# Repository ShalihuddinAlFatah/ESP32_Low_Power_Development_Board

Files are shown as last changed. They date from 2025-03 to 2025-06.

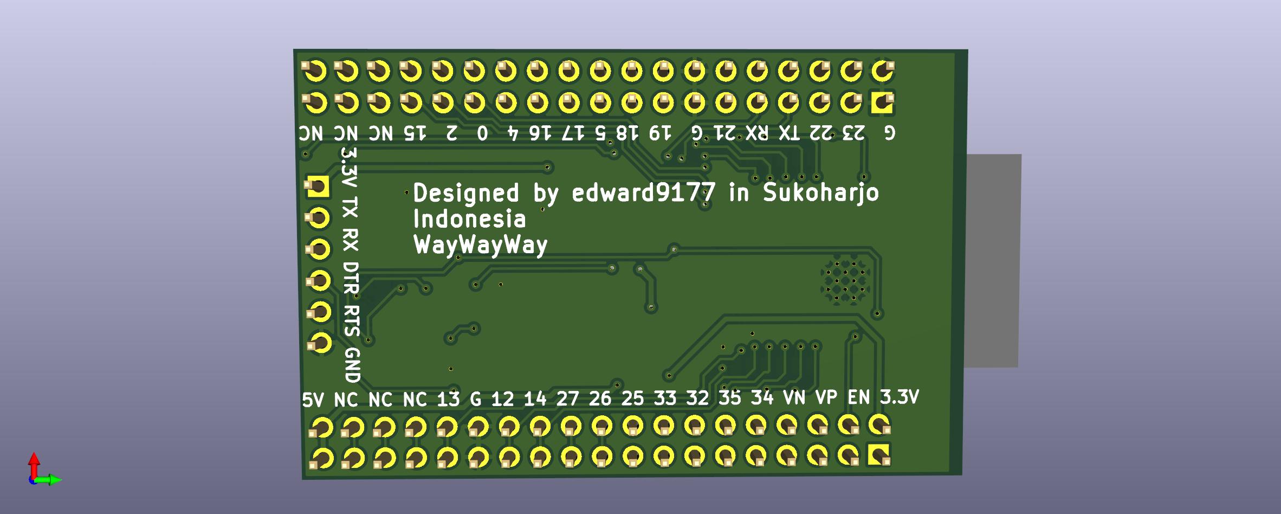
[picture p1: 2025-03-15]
Picture and PDF/ESP32-WROOM-32E_Custom_Dev_Board Bottom.jpg

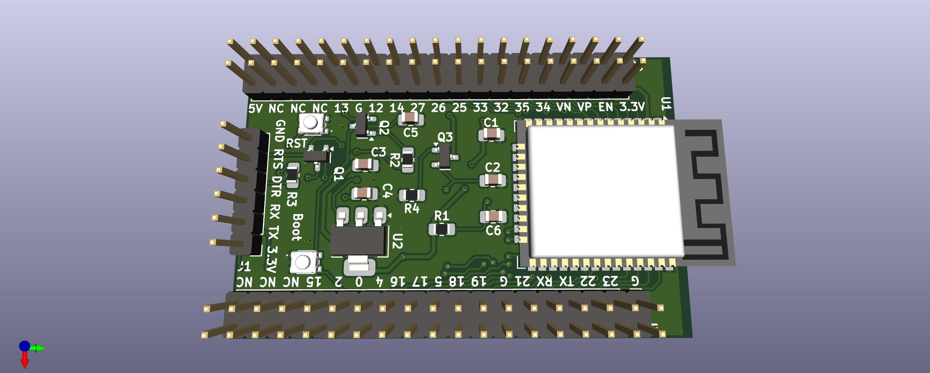
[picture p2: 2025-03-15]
Picture and PDF/ESP32-WROOM-32E_Custom_Dev_Board Top.jpg

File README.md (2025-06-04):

# ESP32_Low_Power_Development_Board

Simple ESP32 development board specifically designed for low power project. 
1. This PCB doesn't have on-board USB to TTL and any LED light. It allows to accurately measure current consumption of your low power IoT project. 
2. Each I/O has 2 pin headers, one for connecting to peripherals and one for troubleshooting purpose (Logic analyzer, oscilloscope, etc).
3. Clearance and creepage minimum 0.2mm (IPC-2221A).
4. Boot and reset button.  

You can find the overview of the schematic and the PCB file in 'Picture and PDF' directory

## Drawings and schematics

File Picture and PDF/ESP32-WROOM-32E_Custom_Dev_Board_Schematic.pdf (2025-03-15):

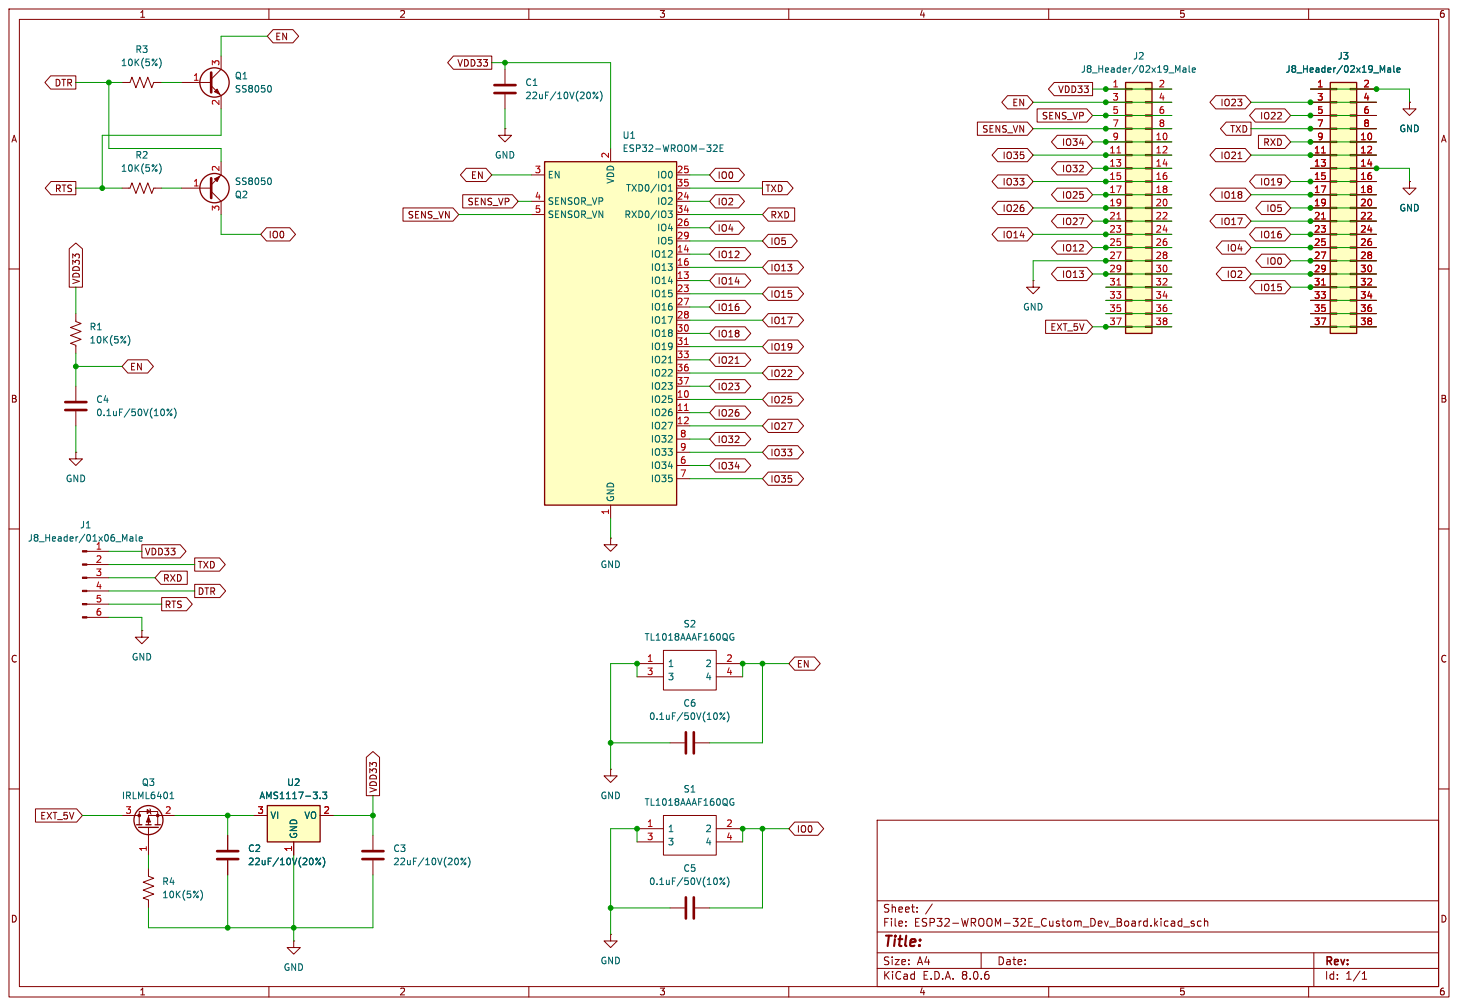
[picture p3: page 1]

Id: 1/1 Title: File: ESP32-WROOM-32E_Custom_Dev_Board.kicad_sch Sheet: / C6

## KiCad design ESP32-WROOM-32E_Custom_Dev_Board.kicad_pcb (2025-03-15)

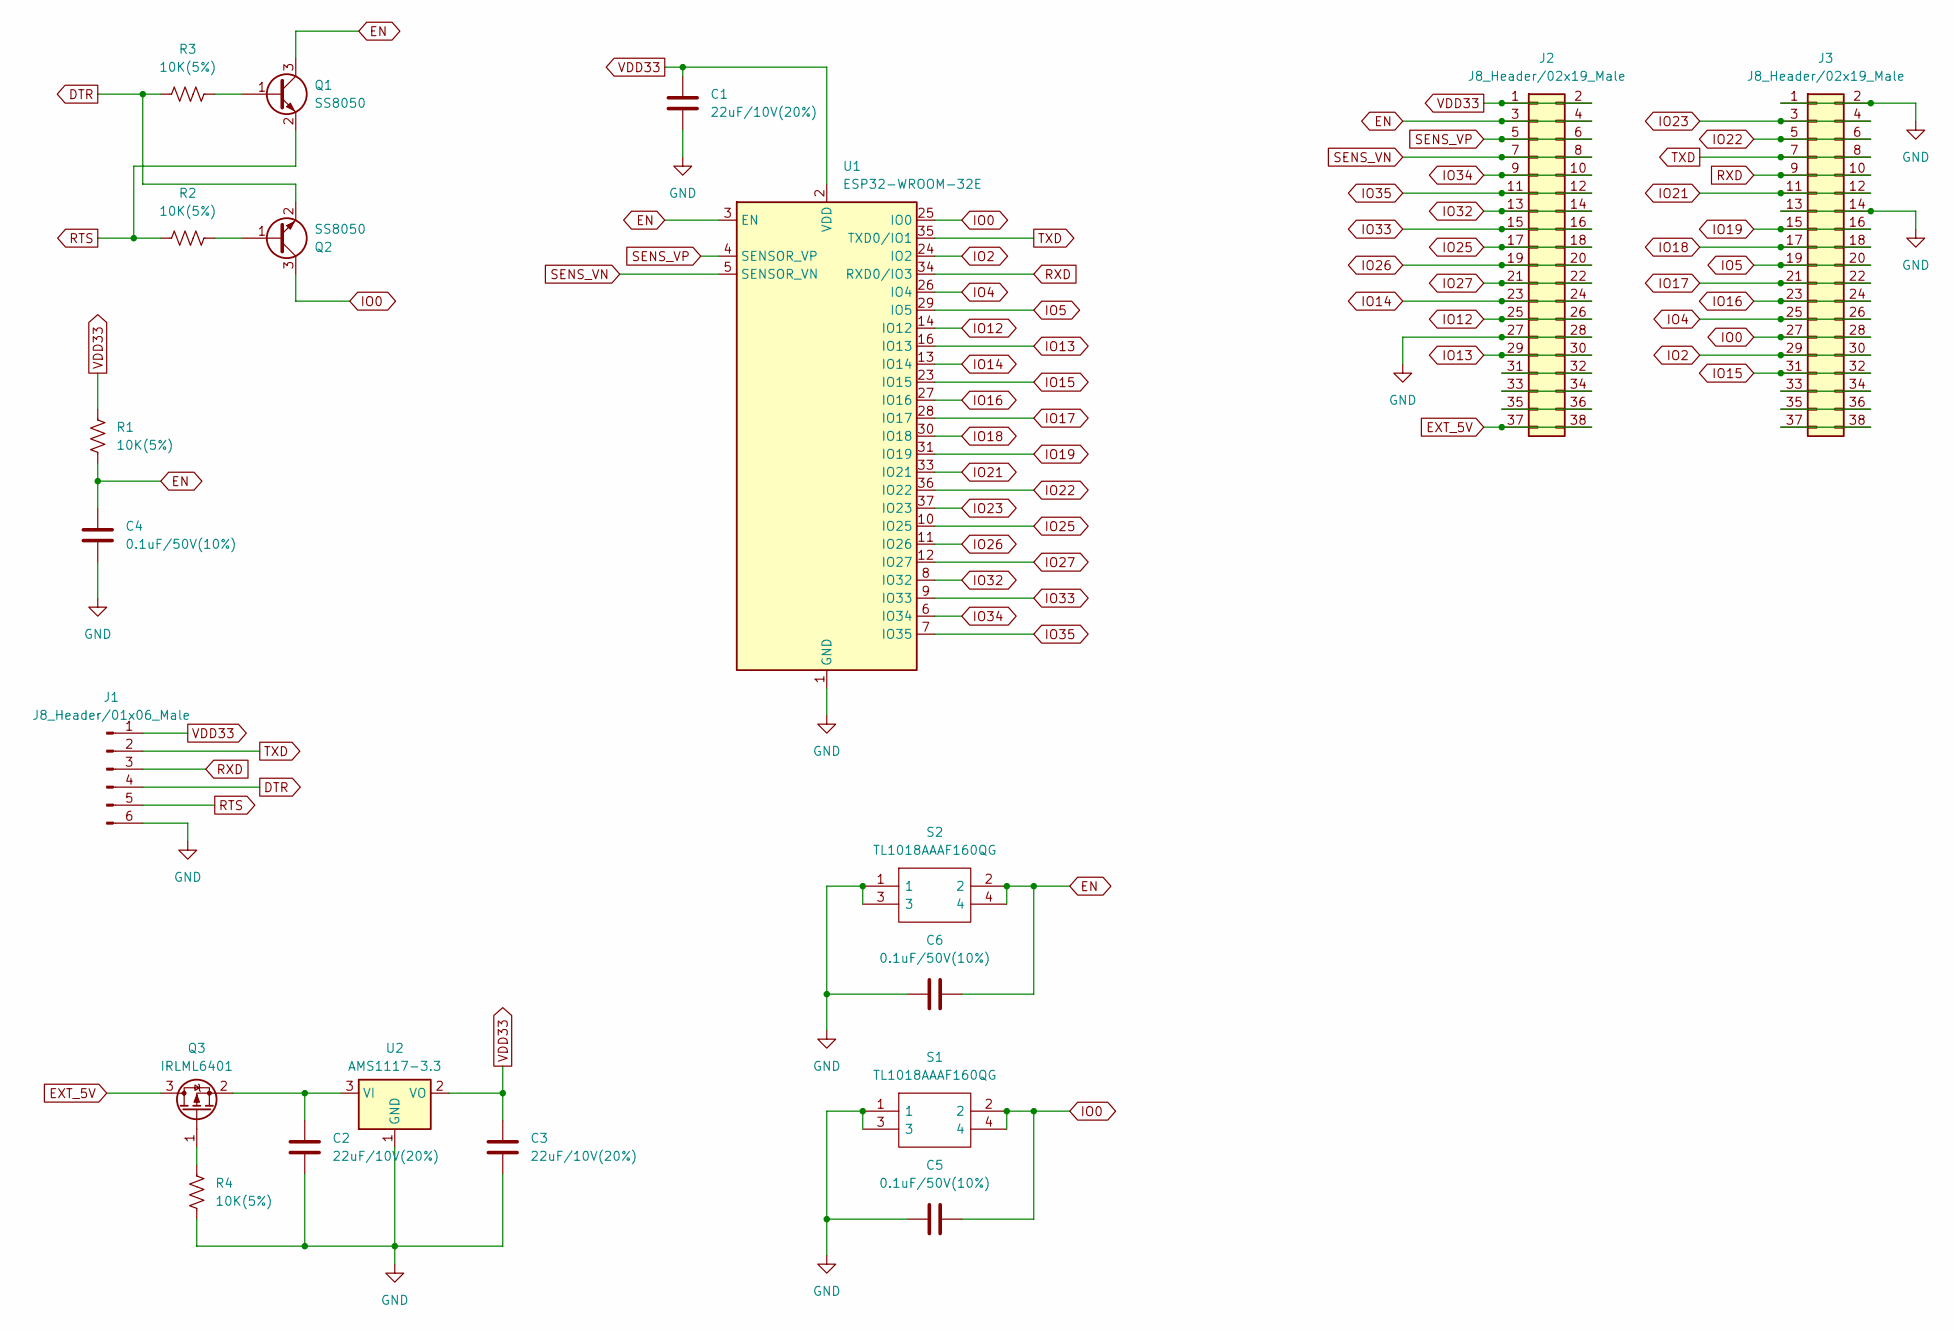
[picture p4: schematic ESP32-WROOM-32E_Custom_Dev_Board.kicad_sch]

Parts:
C1, C2, C3: 22uF/10V(20%); C_0805_2012Metric_Pad1.18x1.45mm_HandSolder
C4, C5, C6: 0.1uF/50V(10%); C_0805_2012Metric_Pad1.18x1.45mm_HandSolder
J1: J8_Header/01x06_Male; PinHeader_1x06_P2.54mm_Vertical
J2, J3: J8_Header/02x19_Male; PinHeader_2x19_P2.54mm_Vertical
Q1, Q2: SS8050; SOT-23
Q3: IRLML6401; SOT-23
R1, R2, R3, R4: 10K(5%); R_0805_2012Metric_Pad1.20x1.40mm_HandSolder
S1, S2: TL1018AAAF160QG; Mouser Part Number 612-TL1018AAAF160QG
U1: ESP32-WROOM-32E
U2: AMS1117-3.3; SOT-223-3_TabPin2

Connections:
DTR: J1.4, Q2.2 (E), R3.1
EN: C4.1, C6.2, J2.3, J2.4, Q1.3 (C), R1.2, S2.2, S2.4, U1.3 (EN)
EXT_5V: J2.37, J2.38, Q3.3 (D)
GND: C1.2, C2.2, C3.2, C4.2, C5.1, C6.1, J1.6, J2.27, J2.28, J3.1, J3.2, J3.13, J3.14, R4.2, S1.1, S1.3, S2.1, S2.3, U1.1 (GND), U1.15 (GND), U1.38 (GND), U1.39 (GND), U2.1 (GND)
IO0: C5.2, J3.27, J3.28, Q2.3 (C), S1.2, S1.4, U1.25 (IO0)
IO2: J3.29, J3.30, U1.24 (IO2)
IO4: J3.25, J3.26, U1.26 (IO4)
IO5: J3.19, J3.20, U1.29 (IO5)
IO12: J2.25, J2.26, U1.14 (IO12)
IO13: J2.29, J2.30, U1.16 (IO13)
IO14: J2.23, J2.24, U1.13 (IO14)
IO15: J3.31, J3.32, U1.23 (IO15)
IO16: J3.23, J3.24, U1.27 (IO16)
IO17: J3.21, J3.22, U1.28 (IO17)
IO18: J3.17, J3.18, U1.30 (IO18)
IO19: J3.15, J3.16, U1.31 (IO19)
IO21: J3.11, J3.12, U1.33 (IO21)
IO22: J3.5, J3.6, U1.36 (IO22)
IO23: J3.3, J3.4, U1.37 (IO23)
IO25: J2.17, J2.18, U1.10 (IO25)
IO26: J2.19, J2.20, U1.11 (IO26)
IO27: J2.21, J2.22, U1.12 (IO27)
IO32: J2.13, J2.14, U1.8 (IO32)
IO33: J2.15, J2.16, U1.9 (IO33)
IO34: J2.9, J2.10, U1.6 (IO34)
IO35: J2.11, J2.12, U1.7 (IO35)
unnamed: J2.31, J2.32
unnamed: J2.33, J2.34
unnamed: J2.35, J2.36
unnamed: J3.33, J3.34
unnamed: J3.35, J3.36
unnamed: J3.37, J3.38
unnamed: Q1.1 (B), R3.2
unnamed: Q2.1 (B), R2.2
unnamed: Q3.1 (G), R4.1
unnamed: C2.1, Q3.2 (S), U2.3 (VI)
RTS: J1.5, Q1.2 (E), R2.1
RXD: J1.3, J3.9, J3.10, U1.34 (RXD0/IO3)
SENS_VN: J2.7, J2.8, U1.5 (SENSOR_VN)
SENS_VP: J2.5, J2.6, U1.4 (SENSOR_VP)
TXD: J1.2, J3.7, J3.8, U1.35 (TXD0/IO1)
VDD33: C1.1, C3.1, J1.1, J2.1, J2.2, R1.1, U1.2 (VDD), U2.2 (VO)

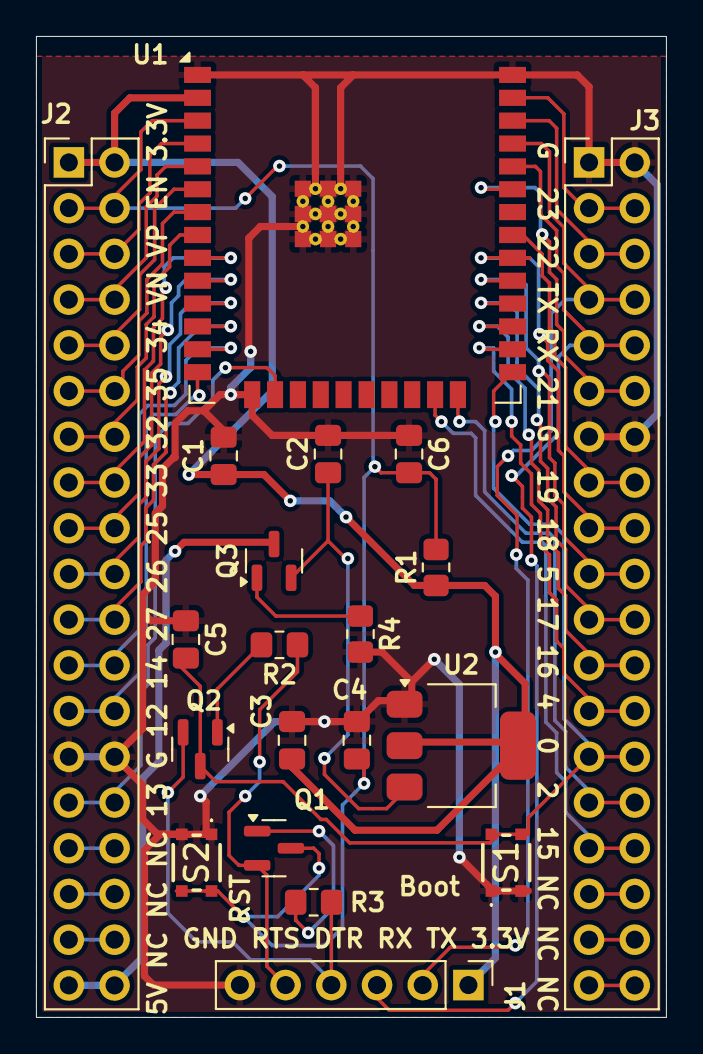
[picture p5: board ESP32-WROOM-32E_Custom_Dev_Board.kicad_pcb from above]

Board: 2 copper layers, 35.0 x 54.5 mm, 20 parts (0 on the bottom side), 42 nets.
